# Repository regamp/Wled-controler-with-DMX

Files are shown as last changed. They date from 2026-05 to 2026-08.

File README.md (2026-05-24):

# WLED Controller with DMX Input

ESP32‑S3 based WLED controller with DMX512 input, fused LED outputs, and a built‑in level shifter – designed for 12V WS2815 LED strips.

## Features

- **MCU**: ESP32‑S3 (WiFi & BLE)
- **DMX512 input** via MAX485
- **4 addressable LED channels**  
  - Each with a 3.3V → 5V level shifter
  - Designed for 12V WS2815 strips (work with others ws281x)
- **4 fuses** – 5A per channel
- **Power supply**  
  - 9-24V DC input  
  - XL1509 buck converter (12V → 5V) for logic


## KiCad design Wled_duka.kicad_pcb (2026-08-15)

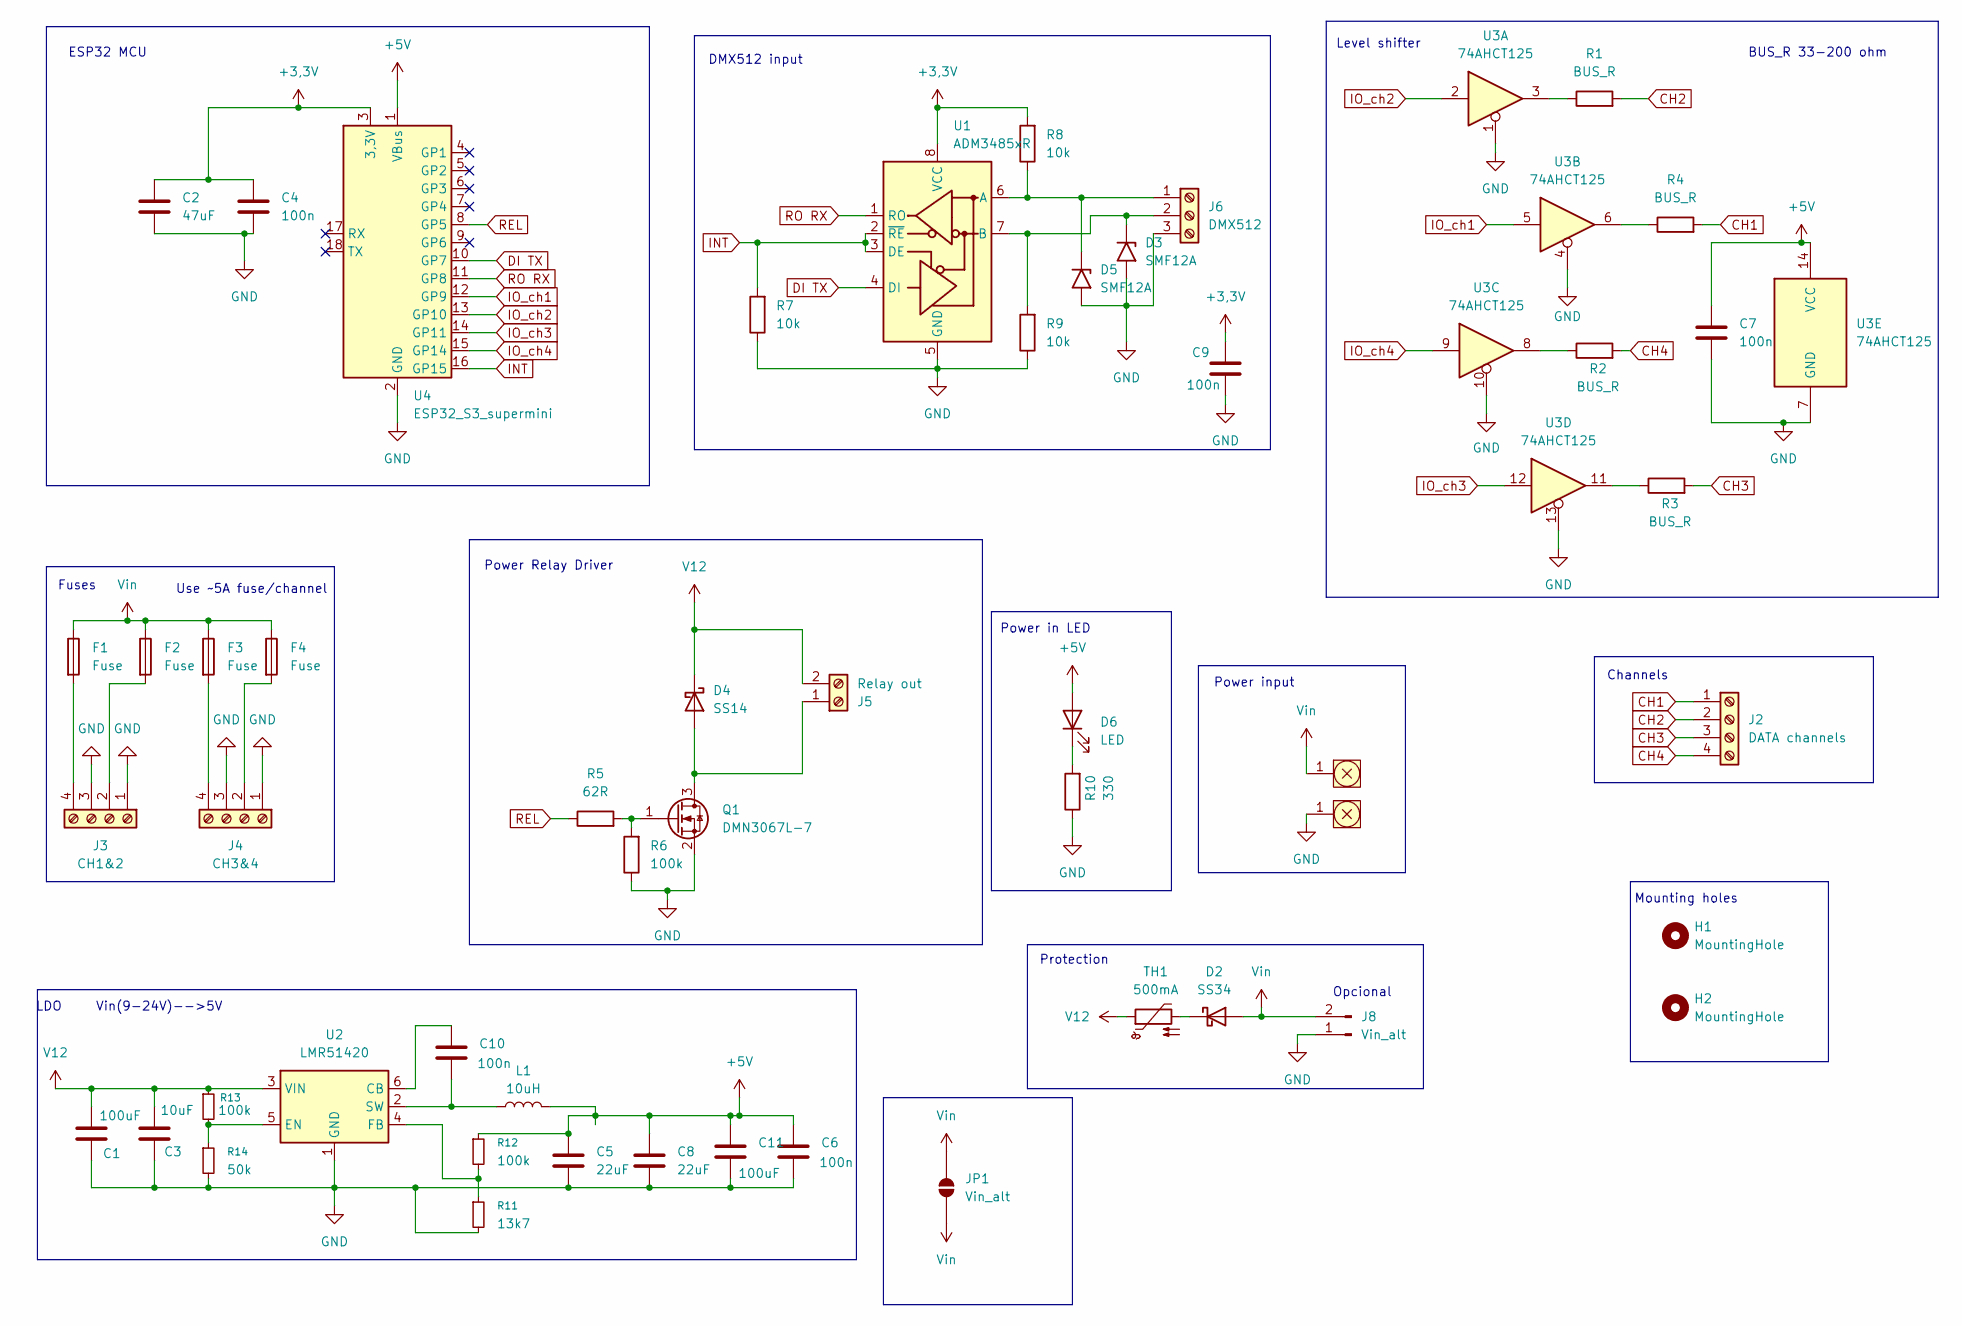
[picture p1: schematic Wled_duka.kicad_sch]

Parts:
C1, C11: 100uF; C_Radial_D5.0mm_H11.0mm_P2.00mm; Mouser Part Number EEU-FR1C101B
C2: 47uF; C_Radial_D5.0mm_H7.0mm_P2.00mm; Mouser Part Number 667-EEU-FR1C101B
C3: 10uF; C_1206_3216Metric_Pad1.33x1.80mm_HandSolder; Mouser Part Number 603-CC1206KKX7GBB106
C4, C6, C7, C9, C10: 100n; C_0805_2012Metric_Pad1.18x1.45mm_HandSolder; Mouser Part Number 603-AC0805KKX7R9BB10
C5, C8: 22uF; C_1210_3225Metric_Pad1.33x2.70mm_HandSolder; Mouser Part Number 603-CC121KKX7R8BB226
D2: SS34; D_SMA_Handsoldering; Mouser Part Number 821-SS34ALH
D3, D5: SMF12A; D_SMF; Mouser Part Number 576-SMF12A
D4: SS14; D_SMA; Mouser Part Number 821-SS14MH
D6: LED; LED_0805_2012Metric_Pad1.15x1.40mm_HandSolder; Mouser Part Number 859-LTST-C170KGKT
F1, F2, F3, F4: Fuse; 35222; Mouser Part Number 534-3522-2
H1, H2: MountingHole; MountingHole_5.3mm_M5_Pad
J1, J7: 7775-2; Keystone_77752; Mouser Part Number 534-7775
J2: DATA channels; TerminalBlock_Degson_DG250-3.5-04P_1x04_P3.50mm_45Degree; Mouser Part Number 490-TBL002A3504GY2GY
J3: CH1&2; TerminalBlock_Ningbo-Kagnex_HB9500_1x04_P9.5mm; Mouser Part Number 523-YK4410400000G
J4: CH3&4; TerminalBlock_Ningbo-Kagnex_HB9500_1x04_P9.5mm; Mouser Part Number 523-YK4410400000G
J5: Relay out; TerminalBlock_Phoenix_PT-1,5-2-3.5-H_1x02_P3.50mm_Horizontal; Mouser Part Number 179-TB0011-350-02GR
J6: DMX512; TerminalBlock_Phoenix_PT-1,5-3-3.5-H_1x03_P3.50mm_Horizontal; Mouser Part Number 179-TB0011-350-03GR
J8: Vin_alt; PinHeader_1x02_P2.54mm_Vertical
JP1: Vin_alt; SolderJumper-2_P1.3mm_Open_RoundedPad1.0x1.5mm
L1: 10uH; L_Bourns_SRN6045TA; Mouser Part Number 652-SRN4018-100M
Q1: DMN3067L-7; SOT-23; Mouser Part Number 621-DMN3067LW7
R1, R2, R3, R4: BUS_R; R_0805_2012Metric_Pad1.20x1.40mm_HandSolder; Mouser Part Number 603-AC0805FR-7W62RL
R5: 62R; R_0805_2012Metric_Pad1.20x1.40mm_HandSolder; Mouser Part Number 603-AC0805FR-7W62RL
R6: 100k; R_0805_2012Metric_Pad1.20x1.40mm_HandSolder; Mouser Part Number 603-AC0805FR-07100KL
R7, R8, R9: 10k; R_0805_2012Metric_Pad1.20x1.40mm_HandSolder; Mouser Part Number 603-AC0805FR-1010KL
R10: 330; R_0805_2012Metric_Pad1.20x1.40mm_HandSolder; Mouser Part Number 603-AC0805FR-07330RL
R11: 13k7; R_0805_2012Metric_Pad1.20x1.40mm_HandSolder
R12, R13: 100k; R_0805_2012Metric_Pad1.20x1.40mm_HandSolder
R14: 50k; R_0805_2012Metric_Pad1.20x1.40mm_HandSolder
TH1: 500mA; R_1206_3216Metric_Pad1.30x1.75mm_HandSolder; Mouser Part Number MF-NSMF020-2
U1: ADM3485xR; SOIC-8_3.9x4.9mm_P1.27mm; Mouser Part Number 584-ADM3485EARZ
U2: LMR51420; SOT-23-6_Handsoldering; Mouser Part Number 595-LMR51420XFDDCR
U3: 74AHCT125; SOIC-14_3.9x8.7mm_P1.27mm; Mouser Part Number 771-74HCT125D-T
U4: ESP32_S3_supermini

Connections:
+3,3V: C2.1, C4.1, C9.1, R8.2, U1.8 (VCC), U4.3 (3,3V)
+5V: C5.1, C6.2, C7.1, C8.1, C11.1, D6.2 (A), L1.2, R12.1, U3.14 (VCC), U4.1 (VBus)
CH1: J2.1, R4.2
CH2: J2.2, R1.2
CH3: J2.3, R3.2
CH4: J2.4, R2.2
DI TX: U1.4 (DI), U4.10 (GP7)
GND: C1.2, C2.2, C3.1, C4.2, C5.2, C6.1, C7.2, C8.2, C9.2, C11.2, D3.2 (A2), D5.2 (A2), J3.1, J3.3, J4.1, J4.3, J6.3, J7.1, J8.1, Q1.2 (S), R6.1, R7.1, R9.1, R10.1, R11.2, R14.2, U1.5 (GND), U2.1 (GND), U3.1, U3.4, U3.7 (GND), U3.10, U3.13, U4.2 (GND)
INT: R7.2, U1.2 (~RE), U1.3 (DE), U4.16 (GP15)
IO_ch1: U3.5, U4.12 (GP9)
IO_ch2: U3.2, U4.13 (GP10)
IO_ch3: U3.12, U4.14 (GP11)
IO_ch4: U3.9, U4.15 (GP14)
unnamed: D2.1 (K), TH1.2
unnamed: D3.1 (A1), J6.2, R9.2, U1.7 (B)
unnamed: D4.2 (A), J5.1, Q1.3 (D)
unnamed: D5.1 (A1), J6.1, R8.1, U1.6 (A)
unnamed: D6.1 (K), R10.2
unnamed: F2.2, J3.2
unnamed: F1.2, J3.4
unnamed: F4.2, J4.2
unnamed: F3.2, J4.4
unnamed: Q1.1 (G), R5.2, R6.2
unnamed: R1.1, U3.3
unnamed: R2.1, U3.8
unnamed: R3.1, U3.11
unnamed: R4.1, U3.6
unnamed: C10.2, U2.6 (CB)
unnamed: R13.2, R14.1, U2.5 (EN)
unnamed: R11.1, R12.2, U2.4 (FB)
unnamed: C10.1, L1.1, U2.2 (SW)
REL: R5.1, U4.8 (GP5)
RO RX: U1.1 (RO), U4.11 (GP8)
V12: C1.1, C3.2, D4.1 (K), J5.2, R13.1, TH1.1, U2.3 (VIN)
Vin: D2.2 (A), F1.1, F2.1, F3.1, F4.1, J1.1, J8.2, JP1.1 (A), JP1.2 (B)

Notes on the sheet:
Mounting holes
BUS_R 33-200 ohm
LDO Vin(9-24V)-->5V
Protection
Power input
Power Relay Driver
Level shifter
Fuses
Use ~5A fuse/channel
Power in LED
Opcional
ESP32 MCU
Channels
DMX512 input

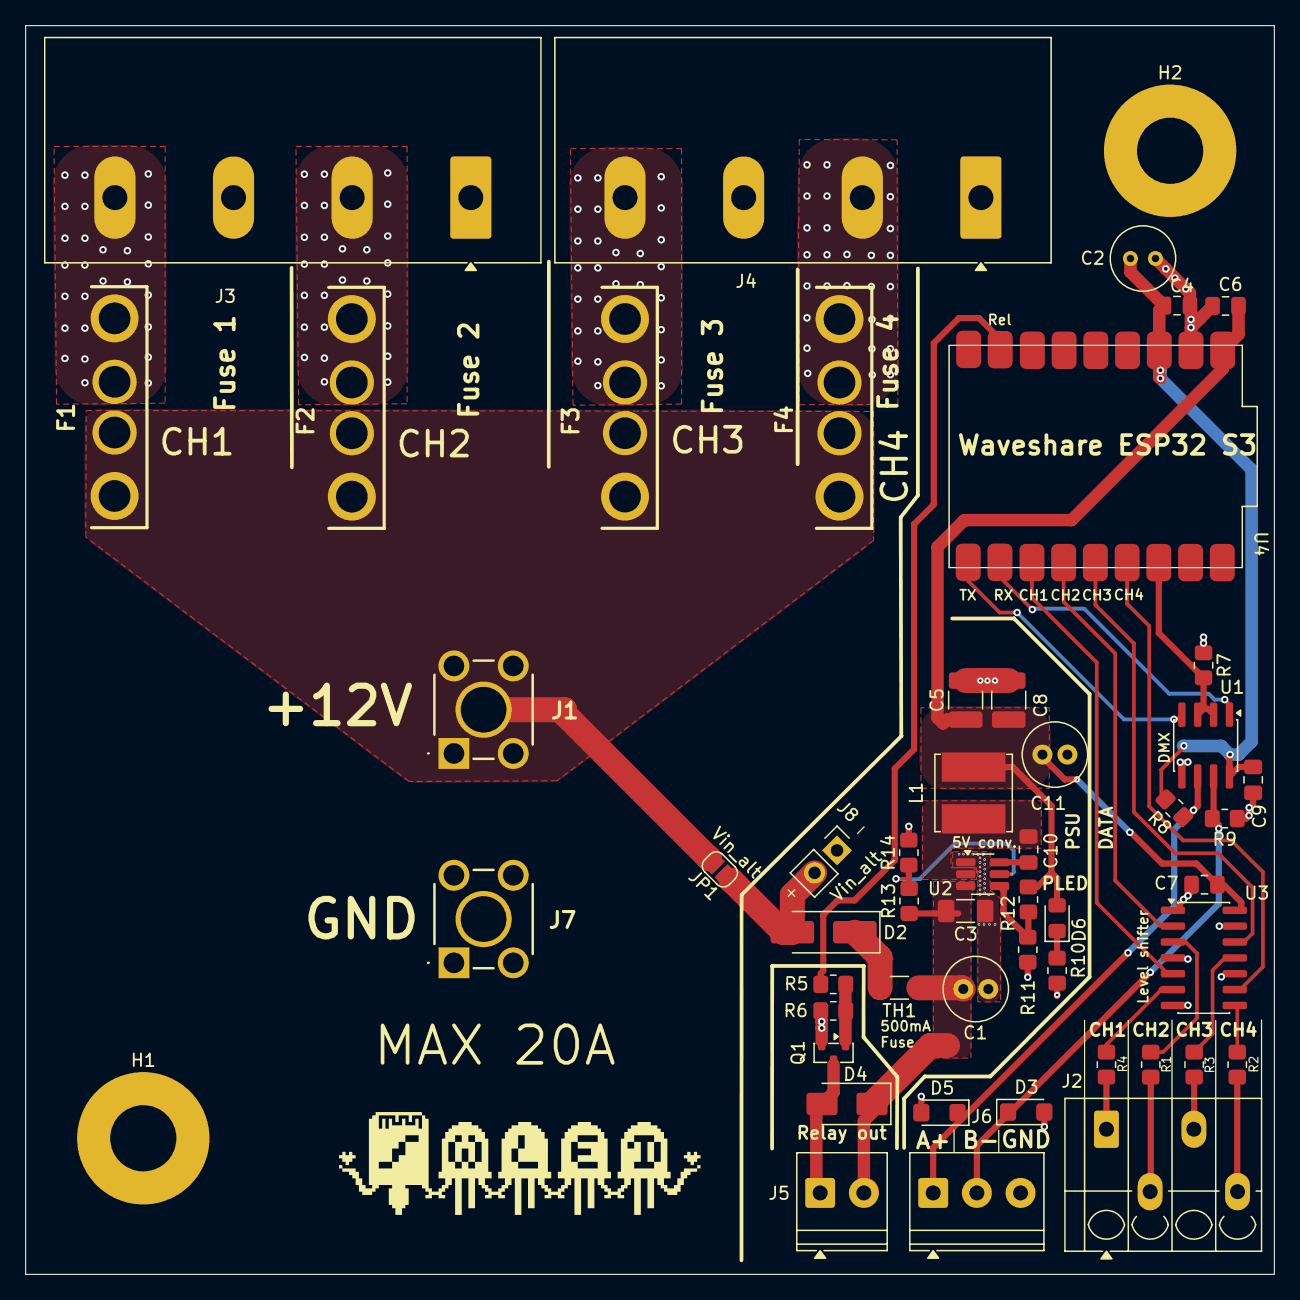
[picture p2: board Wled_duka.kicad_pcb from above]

Board: 2 copper layers, 100.0 x 100.0 mm, 52 parts (0 on the bottom side), 35 nets.

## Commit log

2026-05-24 Update power supply input voltage range in README
2026-05-25 GND fix
    [Wled_duka.kicad_pcb, Wled_duka.kicad_sch]
2026-05-25 Max485 remove --- Max3485 placed
    [Wled_duka.kicad_pcb, Wled_duka.kicad_sch]
2026-05-25 Pullup and Pulldown resistors, 3,3V for max3485
    [Wled_duka.kicad_pcb, Wled_duka.kicad_sch]
2026-06-09 Mouser.com ready components
    [Wled_duka.kicad_pcb, Wled_duka.kicad_sch]
2026-06-10 5V CAP + High current trace
    [Wled_duka.kicad_pcb]
2026-06-11 text fix
    [Wled_duka.kicad_pcb]
2026-07-16 Add FB resistors to DC-DC conv.
    [Wled_duka.kicad_pcb, Wled_duka.kicad_sch]
2026-07-16 C2 fix
    [Wled_duka.kicad_pcb]
2026-08-15 CAN transceiver 100nF cap
    [Wled_duka.kicad_pcb, Wled_duka.kicad_sch]
2026-08-15 Gerber file + BOM list(mouser.com)
    [Wled_duka.kicad_pcb]
